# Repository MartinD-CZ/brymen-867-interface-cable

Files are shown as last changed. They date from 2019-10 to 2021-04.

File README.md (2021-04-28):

# Outdated - see the new revision [here](https://github.com/MartinD-CZ/brymen-867-869-interface-cable-rev20)!

# Brymen 867/869 adapter cable
*see the article [here](http://embedblog.eu/?p=475) or the listing [here](https://www.tindie.com/products/martind/brymen-867869-adapter-cable/)*

## Features
- reads data from Brymen 867/869(s) via infrared
- sends the measurements at 9600 baud via virtual serial port
- output data rate and format adjustable
- activity LED
- you **need **a 3D printed case to use this

*Here's how the finished adapter looks:*
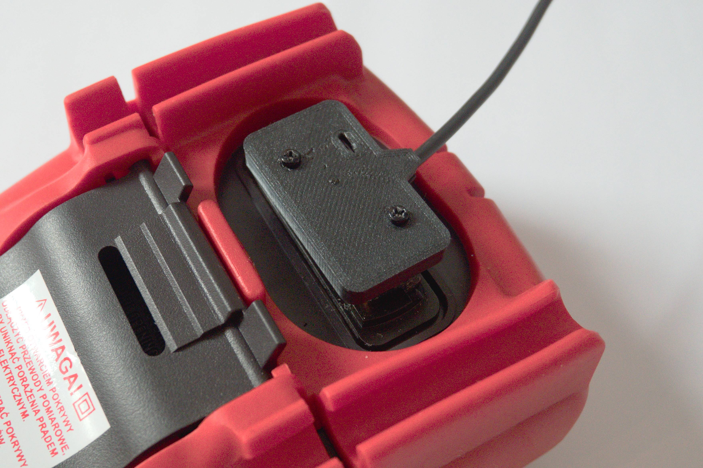
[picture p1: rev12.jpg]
A picture of the finished device


*Here's how the serial output looks:*
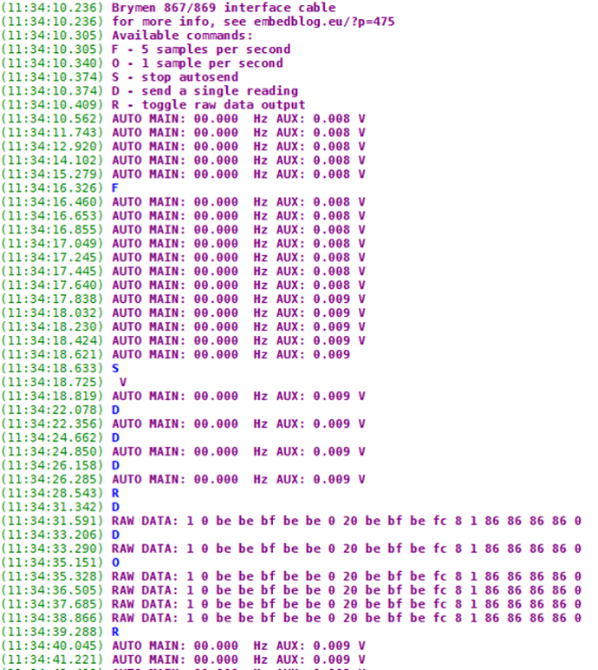
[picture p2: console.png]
Console output


*If you are ordering it without the USB cable (or want to reprogram it), here's the connection diagram:*
Connection diagram

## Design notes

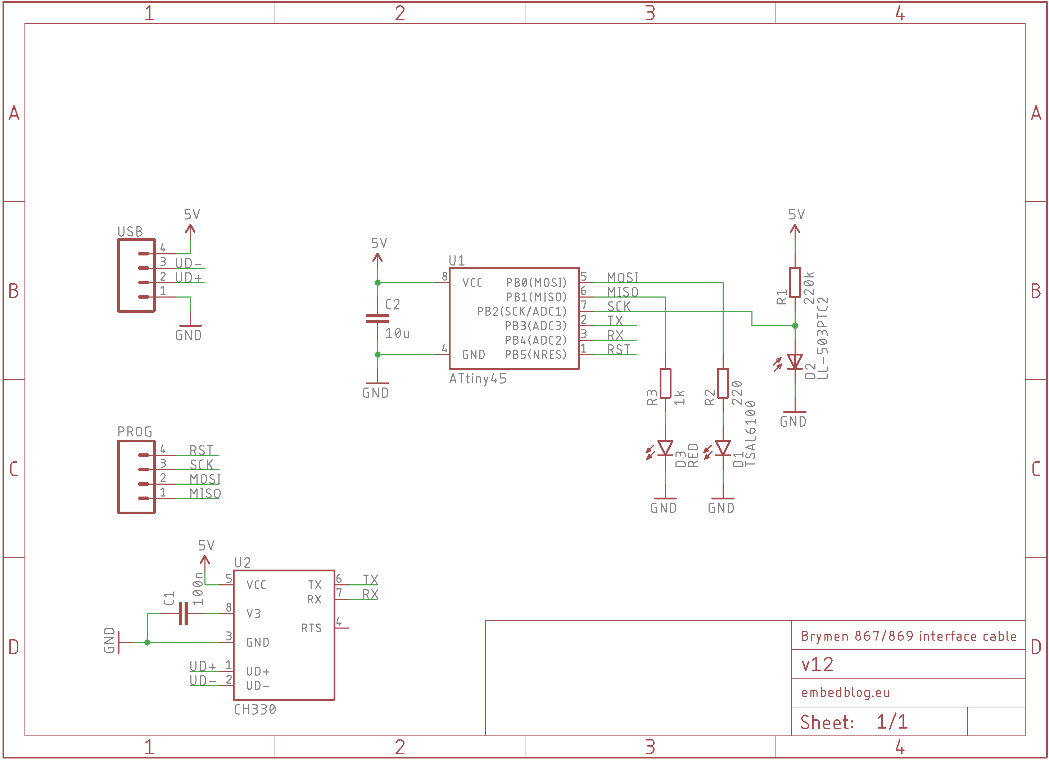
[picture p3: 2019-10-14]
pcb/schematics.png

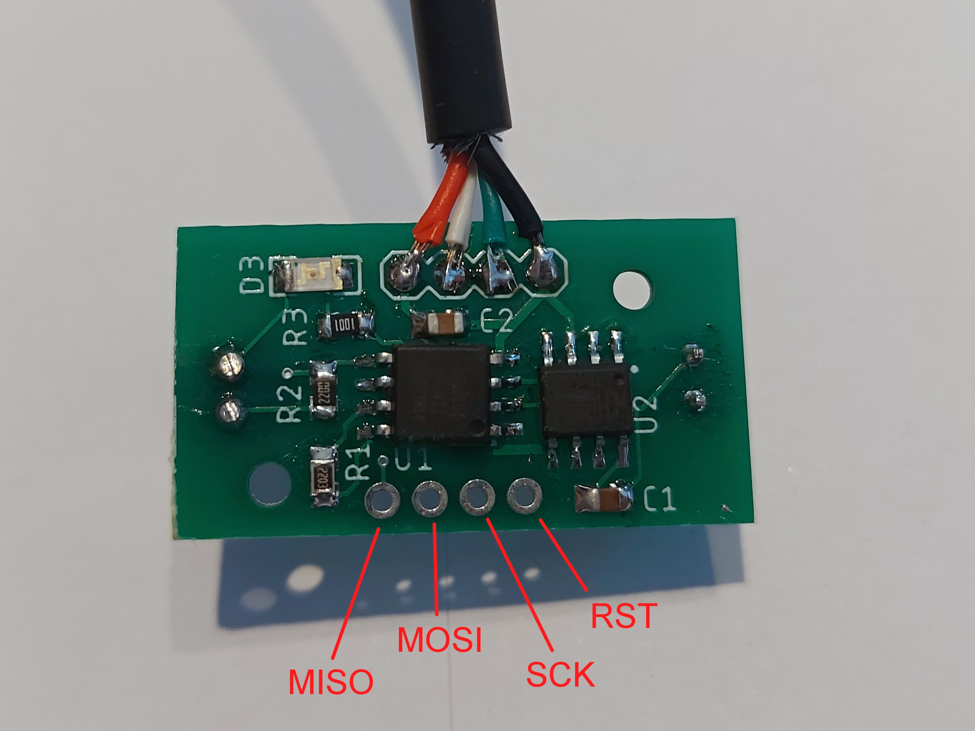
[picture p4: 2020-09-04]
connection_diagram.jpg

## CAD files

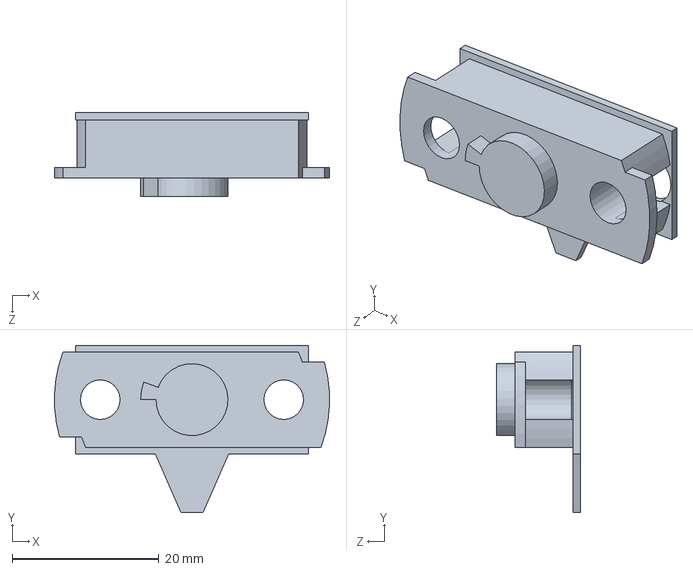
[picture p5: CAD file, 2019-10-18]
case/base.SLDPRT
37.5 x 22.8 x 11.4 mm

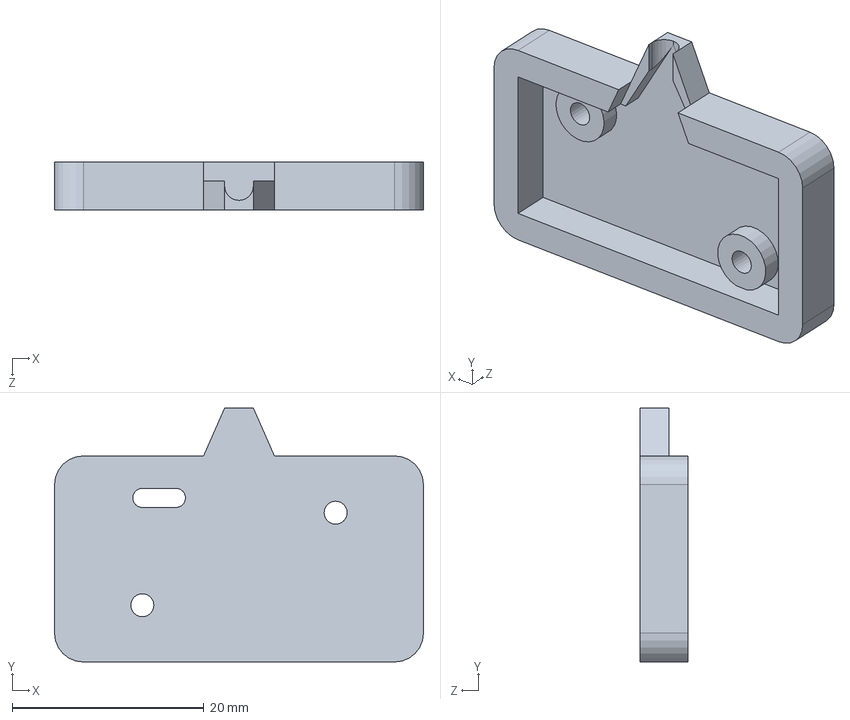
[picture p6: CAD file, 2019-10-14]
case/top.SLDPRT
38.5 x 26.5 x 5.00 mm

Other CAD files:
case/base.STL
case/top.STL

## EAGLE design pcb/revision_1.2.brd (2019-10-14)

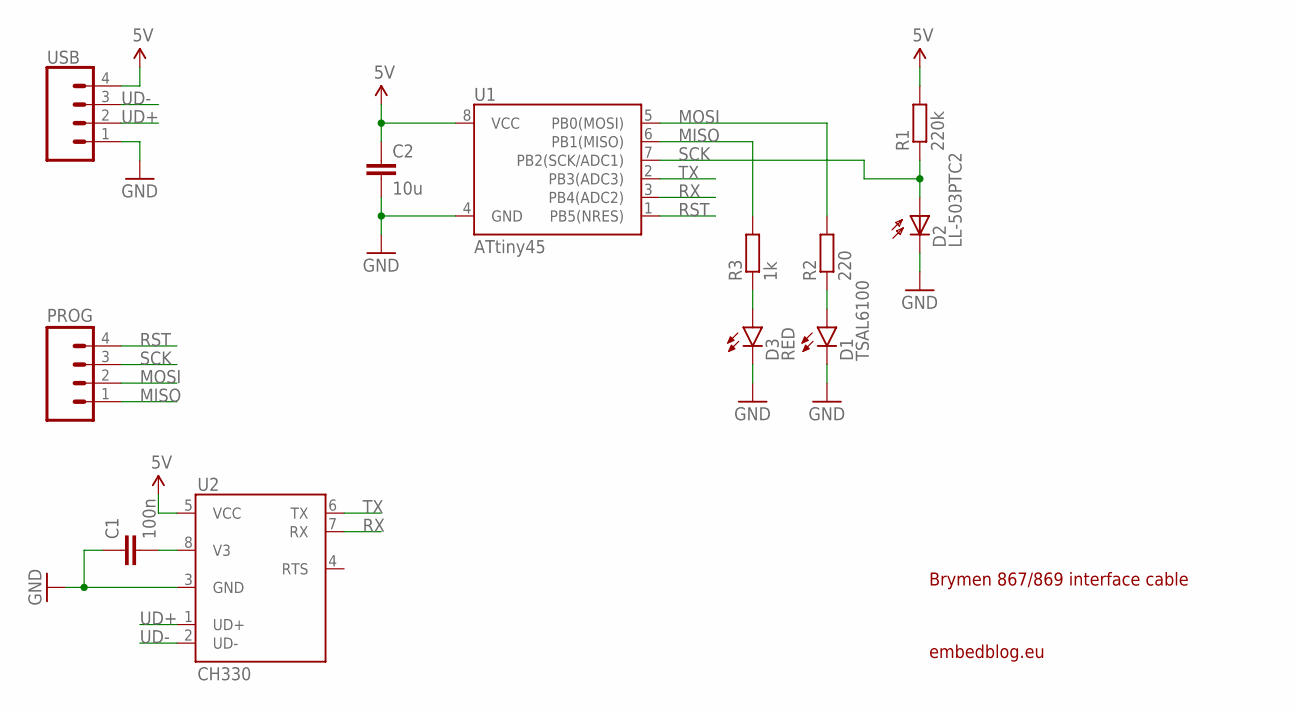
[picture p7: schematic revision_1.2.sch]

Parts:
C1: 100n; C0805
C2: 10u; C0805
D1: TSAL6100; LED5MM
D2: LL-503PTC2; BPX65
D3: RED; LED-1206
PROG: M04NO_SILK_ALL_ROUND; 1X04_NO_SILK_ALL_ROUND
R1: 220k; R0805
R2: 220; R0805
R3: 1k; R0805
U1: ATtiny45; SO08-EIAJ
U2: CH330; SO08
USB: CONN_04; 1X04

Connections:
5V: C2.1, R1.2, U1.8 (VCC), U2.5 (VCC), USB.4
GND: C1.1, C2.2, D1.K (C), D2.K (C), D3.C, U1.4 (GND), U2.3 (GND), USB.1
MISO: PROG.1, R3.2, U1.6 (PB1(MISO))
MOSI: PROG.2, R2.2, U1.5 (PB0(MOSI))
unnamed: C1.2, U2.8 (V3)
unnamed: D1.A, R2.1
unnamed: D3.A, R3.1
RST: PROG.4, U1.1 (PB5(NRES))
RX: U1.3 (PB4(ADC2)), U2.7 (RX)
SCK: D2.A, PROG.3, R1.1, U1.7 (PB2(SCK/ADC1))
TX: U1.2 (PB3(ADC3)), U2.6 (TX)
UD+: U2.1 (UD+), USB.2
UD-: U2.2 (UD-), USB.3

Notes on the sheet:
Brymen 867/869 interface cable
embedblog.eu

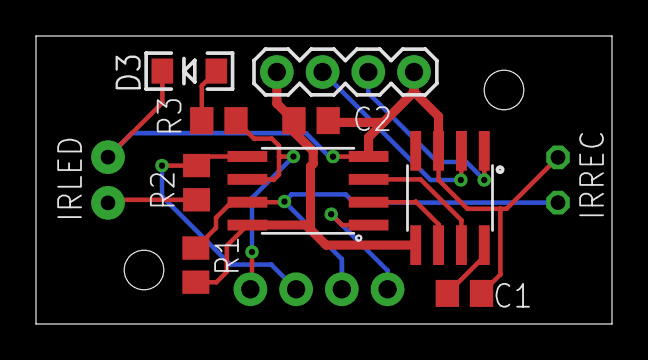
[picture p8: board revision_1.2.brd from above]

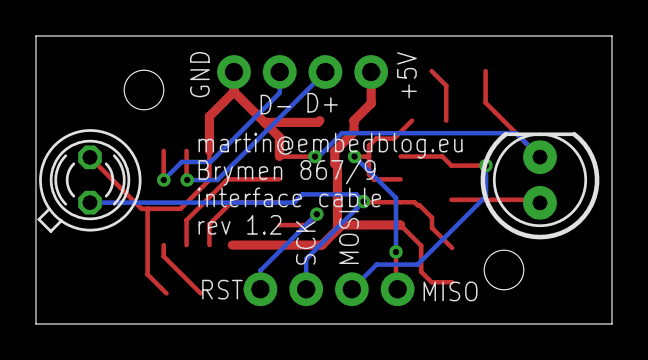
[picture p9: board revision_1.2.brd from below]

Board: 2 copper layers, 32.0 x 16.0 mm, 12 parts (2 on the bottom side), 13 nets.

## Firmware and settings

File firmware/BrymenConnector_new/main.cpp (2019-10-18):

/*
 * BrymenConnector_new.cpp
 * Info: adapter, used to send data from a Brymen 867/9 to a PC using UART
 * Author : martin@embedblog.eu
 * More info: http://embedblog.eu/?p=475
 * IC: ATtiny45
 * Fuses: L0x02 H0xDF E0xFF
 * License:  CC BY-SA 4.0 International
 */ 

#include <avr/io.h>
#include "config.h"
#include <util/delay.h>
#include <avr/pgmspace.h>
#include "softUART/softUART.h"
#include "decoder.h"

extern volatile uint8_t mode;

int main(void)
{
	//setup IO - output for the IR  & activity LEDs
	DDRB |= (1 << DDB0) | (1 << DDB1);

	//input for the phototransistor
	DDRB &=~(1 << DDB2);

	//give the serial terminal a while to react
	_delay_ms(500);		
	
	uart_init();
	uart_sendString_P(PSTR("Brymen 867/869 interface cable\nfor more info, see embedblog.eu/?p=475\n"));
	uart_sendString_P(PSTR("Available commands:\n"));
	uart_sendString_P(PSTR("F - 5 samples per second\n"));
	uart_sendString_P(PSTR("O - 1 sample per second\n"));
	uart_sendString_P(PSTR("S - stop autosend\n"));
	uart_sendString_P(PSTR("D - send a single reading\n"));
	uart_sendString_P(PSTR("R - toggle raw data output\n"));
	
	while (1) 
    {
		if (getData())
		{
			LED_HIGH;
			processData();
			LED_LOW;

			if (mode == MODE_1X_PER_SEC)
				_delay_ms(920);

			if ((mode == MODE_STOP) | (mode == MODE_SEND))
			{
				mode = MODE_STOP;
				while (mode == MODE_STOP);
			}
		}
    }
}

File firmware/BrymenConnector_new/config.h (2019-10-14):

/*
 * config.h
 *
 * Created: 10.10.2019 22:48:01
 *  Author: marti
 */ 


#ifndef CONFIG_H_
#define CONFIG_H_

#define F_CPU				8000000UL

#define UART_BAUD			9600
#define TX_HIGH				PORTB |= (1 << PB4)
#define TX_LOW				PORTB &=~(1 << PB4)
#define RX_LOW				!(PINB & (1 << PB3))
#define UART_DELAY			1000000UL/UART_BAUD

#define IRLED_HIGH	PORTB |= (1 << PB0)
#define IRLED_LOW	PORTB &=~(1 << PB0)
#define IRTRAN_LOW	!(PINB & (1 << PINB2))
#define CLOCK_DELAY	100

#define LED_HIGH	PORTB |= (1 << PB1)
#define LED_LOW		PORTB &=~(1 << PB1)

//modes
#define MODE_5X_PER_SEC		0
#define MODE_1X_PER_SEC		1
#define MODE_STOP			2
#define MODE_SEND			3

#define MODE_DEFAULT		MODE_1X_PER_SEC;

#endif /* CONFIG_H_ */

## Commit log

2018-10-28 V 1.0
    initial commit
    [base.SLDPRT, base.STL, lid.SLDPRT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]
2019-10-14 revision 1.2
    major rework, see blog
    [base.SLDPRT, base.STL, lid.SLDPRT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]
2019-10-18 minor fixes
    [base.SLDPRT, base.STL]

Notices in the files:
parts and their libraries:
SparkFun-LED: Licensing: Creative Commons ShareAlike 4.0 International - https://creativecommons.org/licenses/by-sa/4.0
